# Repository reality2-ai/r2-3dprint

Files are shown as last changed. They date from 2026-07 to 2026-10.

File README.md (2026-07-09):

# Mariko Earthgrids & Reality2 Device Cases

Parametric OpenSCAD enclosures for Mariko Earthgrids field devices, branded with the Reality2 network hallmark.

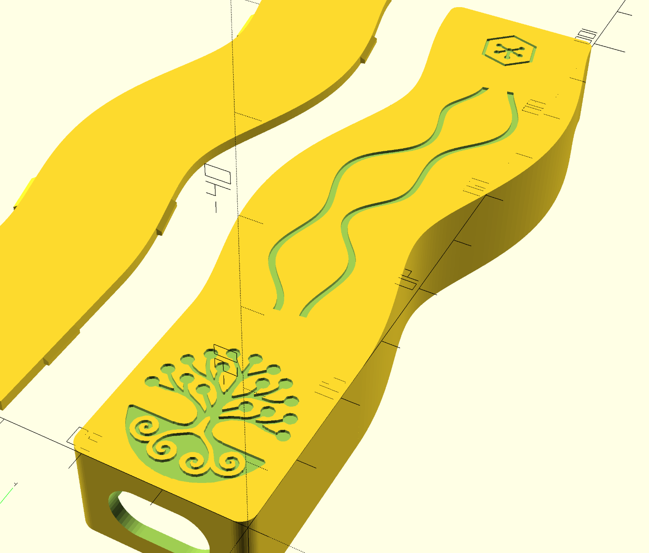
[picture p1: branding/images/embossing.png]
Branding example


## Overview

This repository contains parametric case designs for various Mariko Earthgrids devices. Each device has its own directory with source files, STL exports, documentation, and verification tools.

## Devices

| Device | Description | Status |
|---|---|---|
| [Xiao + LoRa](xiao/) | Phone-mount case for Seeed Xiao + LoRa board | ✅ Production |

## Project Structure

```
mariko-xiao-case/
├── branding/           # Shared branding assets (logos, images)
├── xiao/              # Xiao + LoRa device case
├── CLAUDE.md          # Project context and invariants
└── README.md          # This file
```

## Shared Assets

The `branding/` directory contains shared branding assets used across devices:

- `branding/logos/` - Logo source files (SCAD traces, SVGs)
- `branding/images/` - Reference images and comparisons

### Branding Elements

All Mariko Earthgrids devices carry the Reality2 hallmark and may include:

- **Mariko tree mark** - Auto-traced from the official logo, mirrored to read correctly after installation flip
- **Reality2 hexagon** - Pointy-top ring with hub-and-five-spokes node network (top vertex direction empty)
- **Braided river waves** - Decorative element flowing along device features

Branding is debossed ~0.4mm into visible faces (prints as crisp first-layer engraving). Feature sizes are kept above ~0.45mm for 0.4mm nozzle compatibility.

## Building

All devices use OpenSCAD for parametric design. See individual device directories for:

- Source files (`src/`)
- STL exports (`stl/`)
- Test and preview scenes (`test/`)
- Verification tools (`scripts/`)

## Contributing

When adding a new device:

1. Create a new directory following the structure of existing devices
2. Include source, STL exports, documentation, and verification tools
3. Update this README with the new device entry
4. Document any device-specific invariants in CLAUDE.md

## License

Device-specific licensing is at the discretion of Mariko Earthgrids.

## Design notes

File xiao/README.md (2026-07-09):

# Xiao + LoRa Phone-Mount Case

Parametric OpenSCAD enclosure for a Seeed Xiao + LoRa board that mounts on the back of a phone, connected by a short right-angle USB-C cable. Designed for and branded as a Mariko Earthgrids field device, carrying the Reality2 network hallmark.

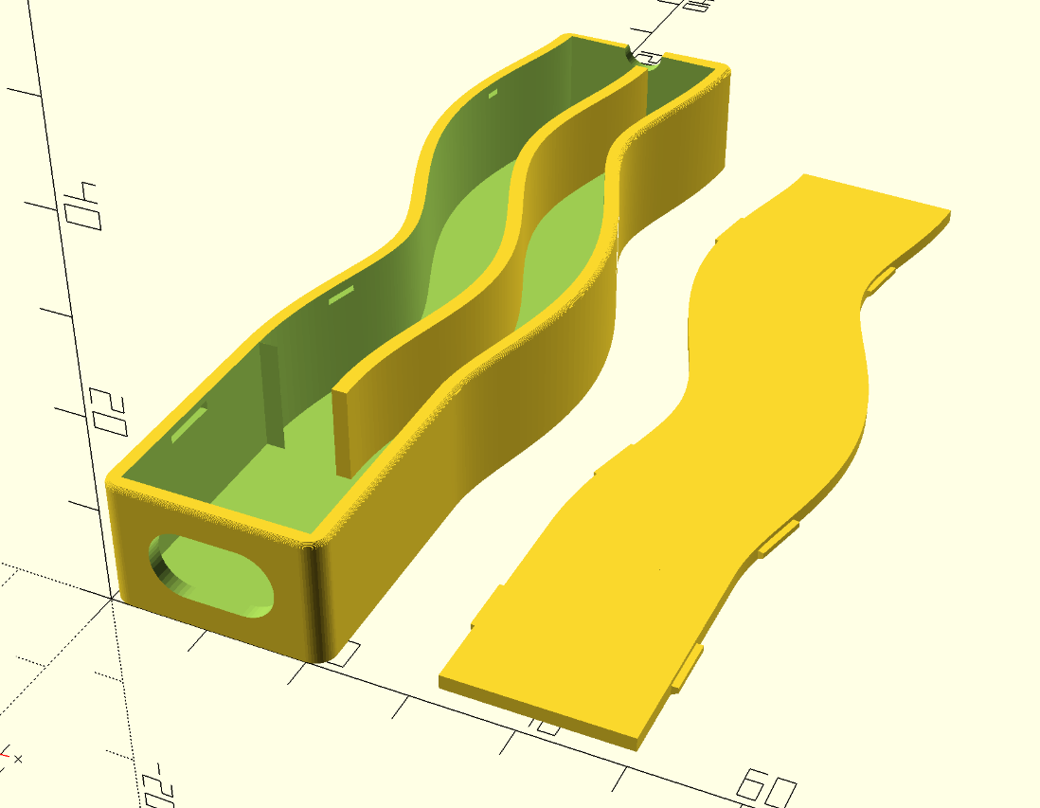
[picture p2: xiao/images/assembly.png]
assembly


## Design overview

- **Inverted mounting**: the solid printed floor is the *visible outer face* when installed; the click-in lid faces the phone. Total profile: **13.1 mm**.
- **Meandering antenna channel, full body width**: the channel is the same outer width as the box, split lengthwise by a central divider into **two 8 mm lanes** — one per antenna (LoRa | WiFi/BLE). 75 mm long; the curve is a smooth function with zero slope at both ends. The divider also serves as the board's central back-stop.
- **One-piece click-in lid** covering box + channel: flat 1.5 mm plate, seated 0.2 mm below the rim, retained by six ramped snap bumps. Pry notch at the channel's far end.
- **Branding, debossed 0.4 mm into the visible face**: Mariko tree mark, braided river waves along the meander, and Reality2 hexagon hallmark.
- **USB-C**: stadium-shaped window (12.6 x 7.0 mm) sized for Adafruit 6367 slim right-angle cable.

## Files

| file | purpose |
|---|---|
| `src/xiao_case.scad` | the design (all parameters at the top) |
| `src/mariko_logo_traced.scad` | traced Mariko tree polygon data — **required dependency** |
| `test/interference.scad` | boolean fit-test scene |
| `test/seated.scad` | preview scene: lid seated on case |
| `scripts/check_fit.py` | snap-fit verification (run before printing) |
| `stl/` | ready-to-print exports |
| `images/` | renders and reference images |

## Printing

- Two parts, both print flat as exported, **no supports**.
- Case: floor on the bed — the branding is bed-face engraving. A 0.2 mm first layer keeps the koru spirals and R2 spokes sharp.
- Lid: prints flat on its top face.
- Material: PLA or PETG. Snap tuning knobs: `tol` (0.3), `snap_depth` (0.7).

## Assembly

1. Seat the board in the box (component side up, USB end at the window).
2. Feed the antennas into the meander trough (left antenna to left lane, right to right lane).
3. Click the lid in: box end first, then press along the channel.
4. Insert the USB-C plug through the window from outside, ribbon toward the rim (phone side).
5. Mount rim-side against the phone.

To open: fingernail in the far-end notch, peel the lid along the channel.

## Verification workflow

Geometry changes should pass the interference test before printing:

```bash
python3 scripts/check_fit.py
```

`closed ~0 mm³` proves the lid seats; `lifted >0` proves all six clips catch.

## Key parameters

All at the top of `src/xiao_case.scad`: board envelope (`board_*`), USB window (`usb_*`), meander (`ant_channel_len/w`, `ant_curve`), shell (`wall`, `floor`), lid/snap (`lid_h`, `seat`, `snap_*`, `tol`), branding (`deboss`, `wave_*`, `hex_*`, `r2_*`), and cosmetics (`corner_r`, `chan_end_r`, `top_round`).

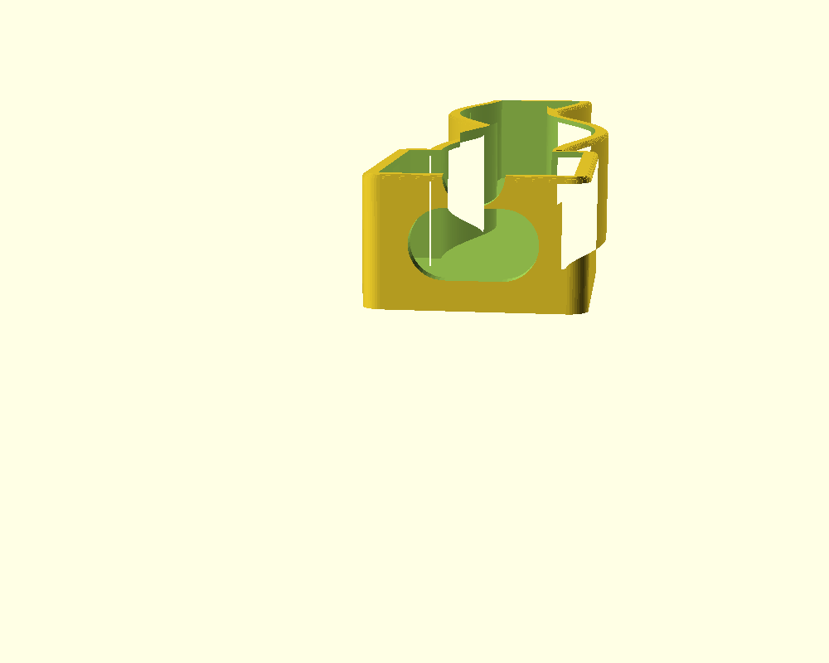
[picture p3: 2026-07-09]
branding/images/usb_face.png

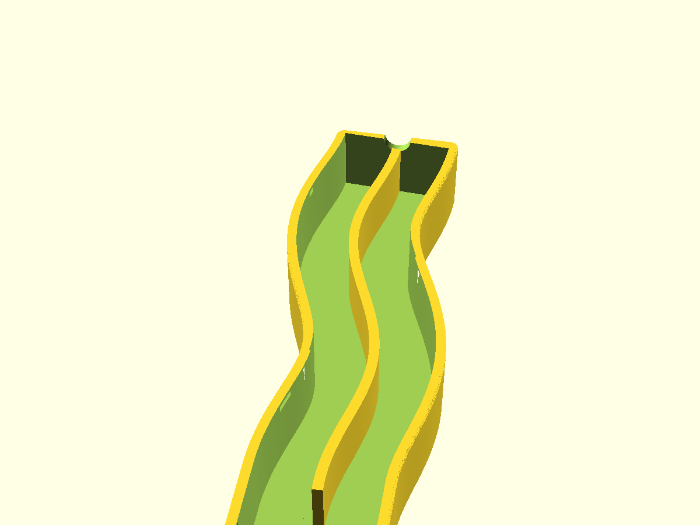
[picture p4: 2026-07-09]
branding/images/lanes.png

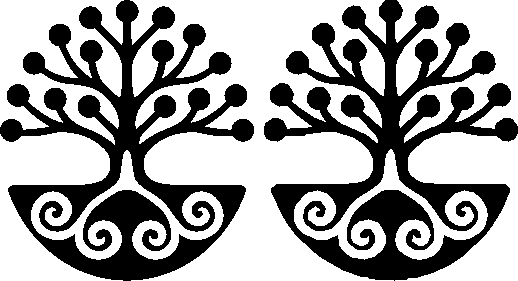
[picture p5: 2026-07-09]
branding/images/trace_compare.png

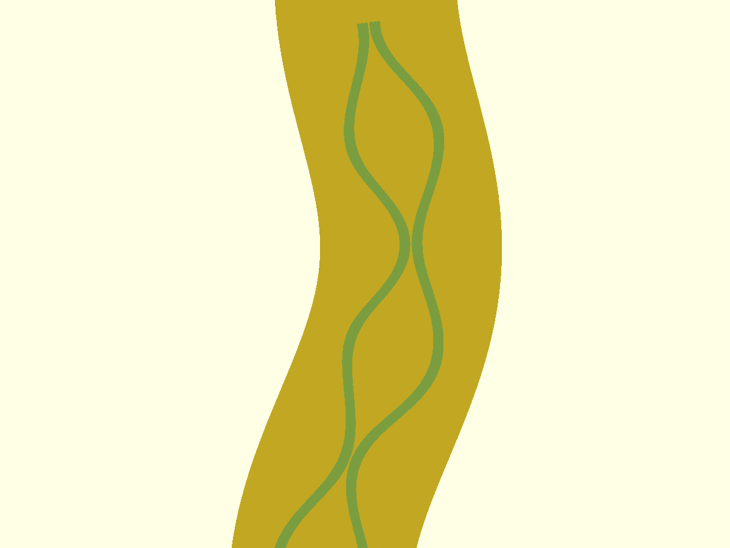
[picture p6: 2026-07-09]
branding/images/visible_face.png

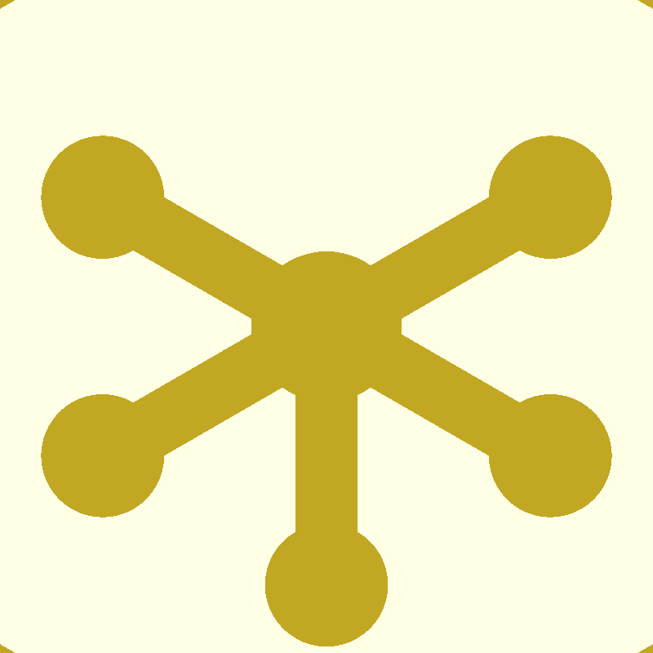
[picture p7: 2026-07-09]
branding/images/r2mark.png

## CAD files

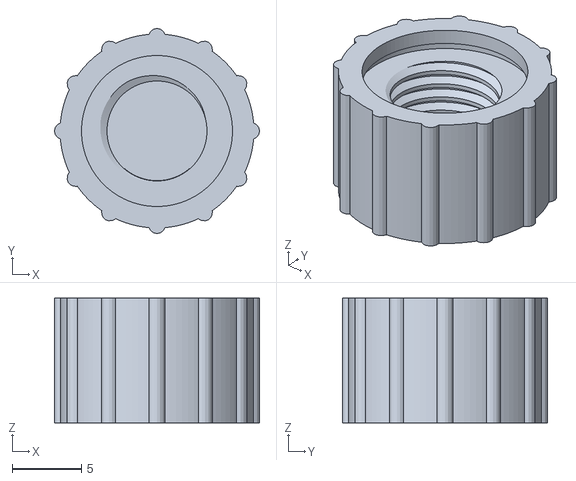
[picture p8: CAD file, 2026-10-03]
M8 cap/M8_captive_cap_v3.stl
14.8 x 14.8 x 9.00

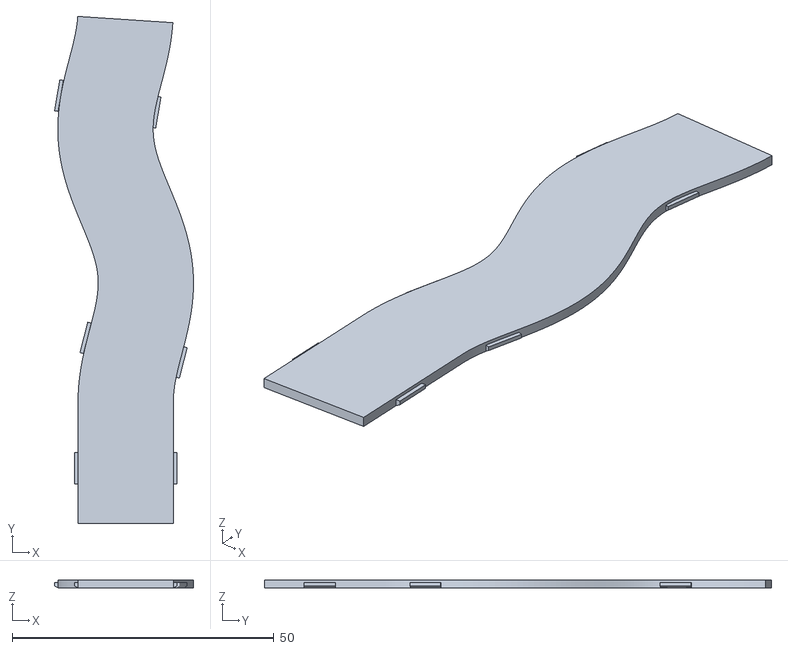
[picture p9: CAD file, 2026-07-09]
xiao/stl/lid.stl
26.5 x 96.8 x 1.50

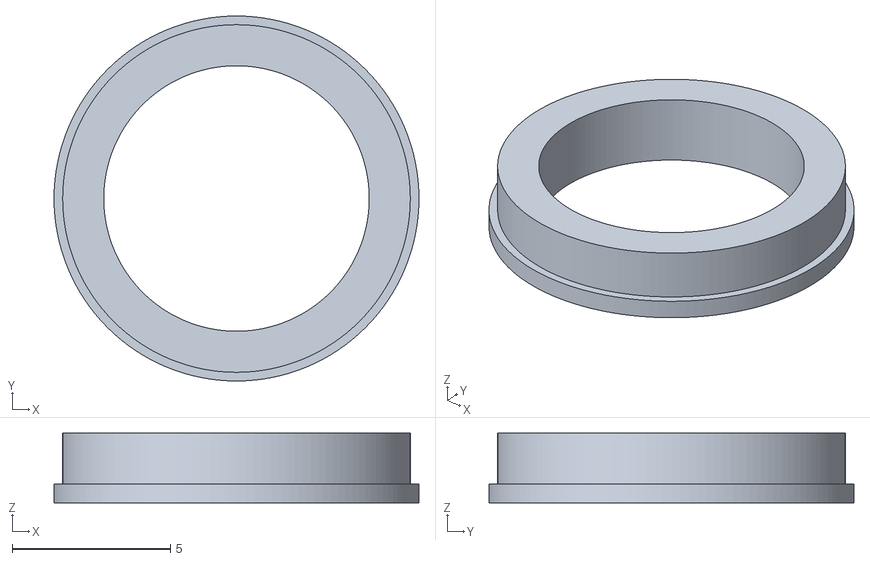
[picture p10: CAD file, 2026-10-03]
M8 cap/M8_captive_gasket_v2.stl
11.6 x 11.6 x 2.20

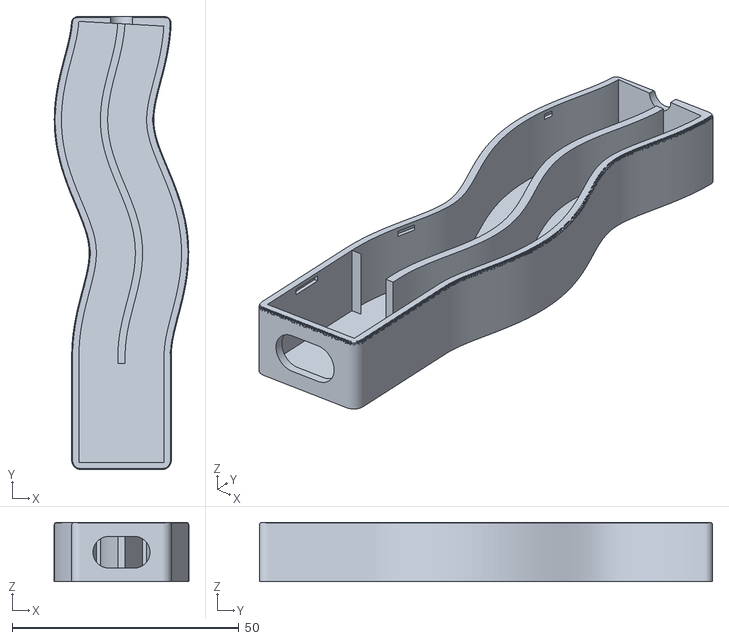
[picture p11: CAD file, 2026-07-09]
xiao/stl/case_body.stl
29.7 x 100.0 x 13.1

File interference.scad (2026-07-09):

use <xiao_case.scad>
lift = 0;
// lid_z0 = outer_h - seat - lid_h = 14.0 - 0.4 - 2.0 = 11.6
intersection(){
    case_body();
    translate([0,0,11.4 + lift]) lid();
}

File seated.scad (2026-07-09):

use <xiao_case.scad>
case_body();
translate([0,0,11.4]) lid();

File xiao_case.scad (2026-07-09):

// =====================================================================
use <mariko_logo_traced.scad>
// Xiao + LoRa phone-mount case  (parametric, OpenSCAD)
// Main box with click-in lid + separate enclosed antenna channel with its
// own click-in lid. USB-C slot (open through floor) on one short side.
// Everything prints flat, opening up -> no supports.
//
// Orientation: board lies flat (X = width 18, Y = length 21, Z = height).
// USB-C on -Y short side; antennas exit +Y short side.
// =====================================================================

// ---------- Board dimensions ----------
board_w      = 18;   // X, short side (with USB / antennas)
board_l      = 21;   // Y, long side
board_h      = 10;   // Z, tallest component clearance

// ---------- USB-C opening ----------
// The case mounts INVERTED on the phone: the solid floor is the visible
// outer face; the lid/rim side faces the phone. The USB opening is a
// closed stadium-shaped window (rounded ends, like the plug's own
// cross-section) in the -Y wall, snug around the slim right-angle USB-C
// plug (Adafruit 6367 / DigiKey 1528-6367-ND), inserted from outside
// after the board is seated. Calliper your plug's overmold and set these
// to overmold + ~0.5mm; FDM holes print slightly undersize.
usb_w        = 12.6; // window width (X), across the rounded ends
usb_h        = 7.0;  // window height (Z) = end radius x 2
usb_z0       = 3.0;  // window lower edge above print-floor

// ---------- Antenna channel (+Y short side) ----------
ant_channel_len = 75;  // how far the channel extends past the case body
ant_channel_w   = 12;  // width of the antenna trough (X)
ant_chamfer     = 1.0; // small 45 chamfer softening the channel->box join

// ---------- Case shell ----------
wall         = 1.6;   // side wall thickness
floor        = 1.2;   // base thickness (thin -> stronger magnet coupling)
clearance    = 0.4;   // gap around board on each side (fit tolerance)

// ---------- Click-in lid ----------
// The lid is a single flat plate that drops INSIDE the walls and clicks
// flush, seated slightly below the rim so the wall tops frame it. Snap
// bumps on the plate edges (ramped underside for press-in, square top for
// retention) engage recesses in the inner wall faces.
lid_h        = 1.5;   // lid plate thickness
seat         = 0.2;   // how far below the rim the lid top sits
snap_depth   = 0.7;   // how far bumps stick out / recesses are cut
snap_h       = 1.0;   // bump/recess height (Z)
snap_z0      = 0;     // bump bottom at the lid underside (max ledge above)
snap_len     = 6;     // bump/recess length along the wall (short: follows curve)
tol          = 0.3;   // clearance between lid edge and wall

// ---------- Print / render ----------
$fn          = 48;
part         = "both";  // "case" | "lid" | "both"

// ---------- Derived ----------
inner_w = board_w + 2*clearance;
inner_l = board_l + 2*clearance;
inner_h = board_h + seat + lid_h + 0.2;  // room above board for the lid
outer_w = inner_w + 2*wall;
outer_l = inner_l + 2*wall;
outer_h = floor + inner_h;               // case body height (rim = top)
lid_z0  = outer_h - seat - lid_h;        // lid underside when seated

// antenna channel shares the box outer height (no vertical step at join)
chan_ow = ant_channel_w + 2*wall;        // channel outer width
chan_oh = outer_h;                       // channel outer height == box
chan_xL = (outer_w - chan_ow)/2;         // channel left edge (X)
chan_xR = (outer_w + chan_ow)/2;         // channel right edge (X)
chan_ih = outer_h - floor;               // channel interior depth

// ---------- Antenna channel meander path ----------
// The channel follows a gentle S-curve (the antennas are flexible wires, so
// the holder can flow like a river). Path parameter t runs 0..ant_channel_len
// from the box back face; lateral offset px(t) has zero slope at both ends
// so the channel leaves the box straight and finishes straight.
ant_curve = 5;   // meander amplitude (max lateral swing ~0.77 * this)

function ch_px(t)  = ant_curve * sin(360*t/ant_channel_len)
                               * sin(180*t/ant_channel_len);
function ch_ang(t) = atan(ch_px(t+0.5) - ch_px(t-0.5));  // local tangent (deg)

// 2D strip of width w following the meander from t0 to t1, drawn in the
// channel-local frame (origin at the box back-face centre, +y = along path).
// o = constant lateral offset of the strip centreline from the path.
module ch_strip(w, t0, t1, o=0, endr=0){
    n = 96;
    pts = concat(
        [for(i=[0:n]) let(t=t0+(t1-t0)*i/n, a=ch_ang(t))
            [ch_px(t) - (o+w/2)*cos(a), t + (o+w/2)*sin(a)]],
        [for(i=[n:-1:0]) let(t=t0+(t1-t0)*i/n, a=ch_ang(t))
            [ch_px(t) - (o-w/2)*cos(a), t + (o-w/2)*sin(a)]]);
    if(endr>0) offset(r=endr) offset(delta=-endr) polygon(pts);
    else polygon(pts);
}

// place children in the local path frame at parameter t (x = lateral,
// y = along-path), in world coordinates
module at_path(t){
    translate([outer_w/2 + ch_px(t), outer_l + t, 0])
        rotate([0,0,-ch_ang(t)])
            children();
}

// ---------- Branding (debossed into the floor's outer face) ----------
deboss     = 0.4;   // engraving depth into the 1.2mm floor (0.8 remains)
wave_amp   = 1.6;   // river wave amplitude
wave_per   = 18;    // river wave period (mm)
wave_w     = 0.9;   // river line width
brand_font = "DejaVu Sans:style=Bold";

// 2D river wave following the meander path: a strip whose centreline sits
// at lateral offset o0 + wave_amp*sin(...) from the path, from t0 to t1
module wave_band(o0, ph, t0, t1){
    n = 90;
    pts = concat(
        [for(i=[0:n]) let(t=t0+(t1-t0)*i/n, a=ch_ang(t),
                          o=o0 + wave_amp*sin(360*t/wave_per + ph))
            [ch_px(t) - (o+wave_w/2)*cos(a), t + (o+wave_w/2)*sin(a)]],
        [for(i=[n:-1:0]) let(t=t0+(t1-t0)*i/n, a=ch_ang(t),
                          o=o0 + wave_amp*sin(360*t/wave_per + ph))
            [ch_px(t) - (o-wave_w/2)*cos(a), t + (o-wave_w/2)*sin(a)]]);
    polygon(pts);
}

// Reality2 hexagon mark, rebuilt from the supplied logo image: a thin
// pointy-top hexagon ring containing a hub-and-spoke node network --
// central node with five spokes radiating toward five of the six vertices
// (the top vertex direction left empty, as in the original). The motif is
// mirror-symmetric in X, so it is unaffected by the installation flip.
hex_R      = 4.2;   // hexagon circumradius (vertex); mark ~8.4mm tall
hex_w      = 0.5;   // ring line width
r2_node_r  = 0.45;  // satellite node radius
r2_hub_r   = 0.55;  // central node radius
r2_spoke_w = 0.45;  // spoke line width
r2_sat_d   = 0.45;  // satellite distance as fraction of hex_R
module hex_mark2d(){
    rotate([0,0,90])   // pointy-top hexagon ring
        difference(){
            circle(r=hex_R,        $fn=6);
            circle(r=hex_R-hex_w,  $fn=6);
        }
    // hub, spokes, satellite nodes (top direction 90 deliberately empty)
    circle(r=r2_hub_r);
    for(ang=[30,150,210,270,330]){
        hull(){
            circle(r=r2_spoke_w/2);
            rotate([0,0,ang]) translate([hex_R*r2_sat_d,0])
                circle(r=r2_spoke_w/2);
        }
        rotate([0,0,ang]) translate([hex_R*r2_sat_d,0])
            circle(r=r2_node_r);
    }
}

// ---------- Mariko tree mark (reconstructed from the logo) ----------
// A stylised tree whose branches end in node-dots, rooted in a half-disc
// mound containing koru spirals (kept as uncut ridges within the debossed
// mound). All strokes >= 0.55mm for 0.4 nozzle printability.
// Natural size: ~13mm wide, ~17mm tall, origin at the mound's flat top.

// recursive branch: strip of length l, width w, node dots at final tips
module twig(l, w, depth){
    hull(){ circle(w/2); translate([0,l]) circle(w*0.4); }
    translate([0,l]){
        if(depth==0) circle(0.9);              // node dot
        else for(a=[-34,34]) rotate(a) twig(l*0.66, w*0.75, depth-1);
    }
}

// koru spiral band (this is the CUT kept clear within the mound)
module koru(rmax=1.7, gap=0.55, turns=1.6){
    n=48; b=rmax/(turns*360);
    pts = concat(
      [for(i=[0:n]) let(th=turns*360*i/n, r=b*th)      [r*cos(th), r*sin(th)]],
      [for(i=[n:-1:0]) let(th=turns*360*i/n, r=b*th+gap)[r*cos(th), r*sin(th)]]);
    polygon(pts);
}

module mariko_tree2d(){
    // mound: lower half-disc, flat top at y=0, minus the koru spirals
    difference(){
        intersection(){
            circle(r=6);
            translate([-7,-7]) square([14,7]);
        }
        translate([-3.1,-2.6]) koru(1.5);
        translate([ 0.1,-3.0]) koru(1.8);
        translate([ 3.2,-2.6]) koru(1.5);
    }
    // tree: trunk + two branch generations + node dots
    twig(4.5, 1.5, 3);
}
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

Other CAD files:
M8 cap/M8_captive_cap_v3.scad
M8 cap/M8_captive_gasket_v2.scad
src/xiao_case.scad
xiao/src/mariko_logo_traced.scad
xiao/src/xiao_case.scad
xiao/test/interference.scad
xiao/test/seated.scad

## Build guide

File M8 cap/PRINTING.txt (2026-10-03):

M8 CAP V3 — use with the V2 TPU gasket.
14mm body diameter, 14.8mm overall across grip ribs, 9mm height.
Same 0.30mm thread clearance and same V2 gasket pocket.
Wall at retaining groove increased from 0.175mm to 1.175mm.
PLA, 0.12mm layers, 4 walls, closed end down, no supports.
Inspect layer preview: outer wall must be continuous around gasket groove.
Check wider cap clears enclosure recess and permits gasket compression
on metal shoulder without contacting surrounding enclosure plastic first.
No water resistance rating established.

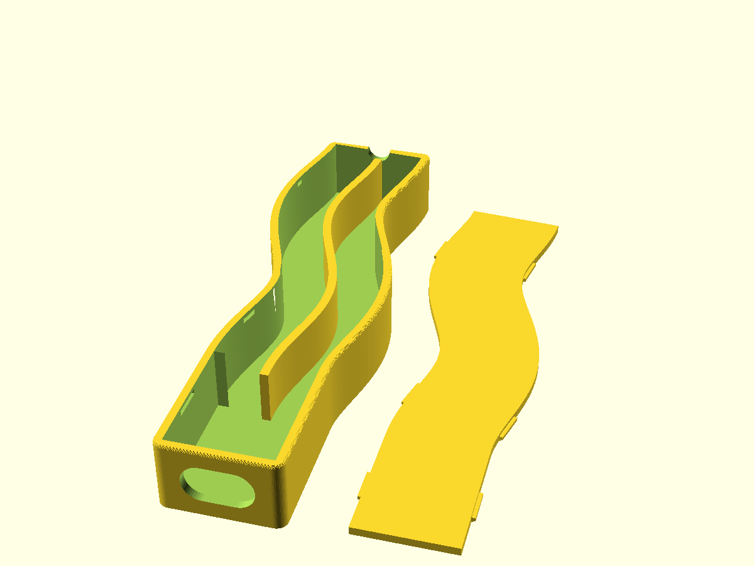
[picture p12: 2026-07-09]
branding/images/assembly.png

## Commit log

2026-07-09 Xiao+LoRa phone-mount case: inverted low-profile body, meander antenna channel, one-piece click-in lid, traced Mariko tree + R2 network hallmark, stadium USB-C window
    - 13.1mm profile, prints flat, no supports
    - six verified snap clips (see scripts/check_fit.py)
    - branding debossed into the bed face, mirrored for installation flip
    [case_body.stl, interference.scad, lid.stl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]
2026-07-09 Reorganize: separate branding from case geometry
    - Move logo files to branding/logos/
    - Move branding reference images to branding/images/
    - Move main case to src/
    - Move test/preview scenes to test/
    - Update include paths in SCAD files
    - Update CLAUDE.md to reflect new structure
    [interference.scad, mariko_logo_traced.scad, seated.scad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]
2026-07-09 Add renders showing current design: pry notch, logo deboss
    - Add test/logo_deboss.scad: shows debossed floor face with branding
    - Add test/pry_notch.scad: detail view of lid removal notch
    - Add test/usb_face.scad: USB side view
    - Regenerate images with current design (pry notch present)
    - Remove obsolete visible_face.png
    [logo_deboss.scad, pry_notch.scad, usb_face.scad]
2026-07-09 Fix logo_deboss scene to show debossed floor face
    - Adjust camera positioning to look from below at floor face
    - Floor face contains Mariko tree, R2 hexagon, and wave debossing
    [logo_deboss.scad]
2026-07-09 Widen antenna channel and add center divider for RF separation
    - Channel now full box width (was 12mm, now ~21mm)
    - Center divider (1.2mm) separates left and right antenna paths
    - Two separate lid ribbons (8mm each) with gap for divider
    - Reduces RF coupling between antennas at LoRa frequencies
    - Snap-fit verified: closed 0.26mm³, lifted 3.1mm³ (PASS)
    - Update check_fit.py for new file structure
    [case_body.stl, lid.stl, xiao_case.scad]
2026-07-09 Reorganize for multi-device structure
    - Move Xiao case files into xiao/ directory
    - Create xiao/images/ for device-specific renders
    - Add xiao/README.md with device documentation
    - Update main README.md for multi-device overview
    - Update CLAUDE.md with project structure and device invariants
    - Update file paths in SCAD files and check_fit.py
    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
    [case_body.stl, interference.scad, lid.stl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]
2026-07-09 Add logo_deboss scene and render showing debossed floor face
    [logo_deboss.scad]
2026-07-09 Simplify main README, add branding details, remove duplicate logo_deboss
    - Update main README to be more general with less Xiao detail
    - Add branding elements section to main README
    - Add embossing.png to xiao README
    - Remove duplicate logo_deboss files (using embossing.png instead)
    [logo_deboss.scad]
2026-07-09 Update CLAUDE.md for r2-3dprint repo
    - Update project name from mariko-xiao-case to r2-3dprint
    - Add GitHub repository URL
    - Update check_fit.py command to use cd xiao
    - Add branding elements section with logo tracing guidelines
    - Clarify shared branding assets usage
2026-10-03 Add M8 captive cap and gasket models
    [M8_captive_cap_v3.scad, M8_captive_cap_v3.stl, M8_captive_gasket_v2.scad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]
2026-10-13 Add printable Reality2 router enclosure with service port covers
2026-10-18 Improve router cover retention and update enclosure print files
2026-10-23 Reinforce router port cover clip roots and ease hook insertion
2026-10-23 Add Pi 3 Heltec router case with GPS holder and dual antenna mounts
2026-10-24 Remove unsupported ledges from Heltec cradle and antenna pads
2026-10-24 Raise Heltec screen and tighten cradle grip
2026-10-29 Add compact two- and three-cell battery holders
2026-10-30 Lengthen battery holders by 1 mm after print fit check
2026-10-31 Add curved battery cradle concepts with copper-tape end walls
2026-10-31 Reinforce curved battery cradles and export checked fit-test STLs
2026-10-31 Add protected-cell holder with 68 mm base and one-ended overhang
2026-10-31 Shorten protected battery holder mounting base to 67 mm
2026-10-31 Add rounded copper-contact bump to protected battery holder
2026-10-31 Increase battery contact preload and add raised polarity marks
2026-10-31 Extend protected battery cradle lips for greater retention
2026-10-31 Add wired battery holder with recessed solder-contact seats
2026-10-31 Retain negative contact bump and place polarity marks below centred wire holes
2026-11-02 Add thermistor groove and lower wired holder pedestal with 1.2 mm floor
2026-11-02 Move thermistor channel to the opposite side
